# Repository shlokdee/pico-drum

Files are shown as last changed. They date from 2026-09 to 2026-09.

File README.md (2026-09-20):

# pico-drum

rpi pico based midi octapad drum... It uses piezos to sense a tap and outputs midi to your computer. 
Its low cost and really easy to build

## Features:
* 8 pads you can map to any drum piece
* Can play using drum sticks
* connects as midi device to your computer
* screw less, you can connect different pieces together with clips
* tpu pads to stop the ceramic disk from shattering on impact with a drumstick

## CAD Model:

[Onshape link](https://cad.onshape.com/documents/cf409ba0d7730449b32f7b00/w/cda78f4cd7516b803366ff83/e/52d1e4e74febc94aa938617d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) <br><br>
Screenshot From 2026-09-18 23-24-44

There is a base plate, on which there are 8 slots to put your pads
The brown and black pads are printed with TPU, and the piezo sensor is sandwiched between them to ensure that it does not break. The bottom plate mounts the pico, multiplexer and the perf board.

## Schematic
Screenshot From 2026-09-18 15-51-26

Raspberry pi pico has only 3 analog ports, hence we have used a multiplexer to connect 8 drum pads. Piezo emits more than 20 volts when struck hard, which could fry the multiplexer and pico. So we use diodes and resistors to cap the voltage to 3.3 volts, which is safe. The resistors and diodes are mounted on a perf board and it is placed in the bottom plate of the enclosure, along with the pico and the multiplexer...

Screenshot From 2026-09-18 23-11-58

The perf board layout

## Firmware:

Run the command 
```
pip3 install adafruit-circuitpython-midi
```

Then Upload the firmware.py to the pico via this guide: 

[Instructions on how to upload to pico](https://tasnimzotder.medium.com/how-to-write-code-on-pi-pico-using-circuitpython-vs-code-9fd7f0bb5d0a)

You can change what midi commands you want to send with each tap by editing the pad_notes variable in the firmware.py

## How to build
Purchase the components listed in [BOM](BOM.csv)
1. Print the topplate and bottomplate in pla, or any other hard plastic filament.
2. Print the tpupad-Part 1 in 10% infill TPU filament, as we want it to be a bit softer and shock absorbing. Print 8 qty
3. Print the tpupad-Part 2 in 30% infill TPU filament, as it needs to be a bit hard for the drum taps. Print 8 qty
4. Print the clips in TPU 10%, as we need to bend them to fit in place. Print 2 qty
5. Solder in the resistors and the diodes onto the perf board according to the schematic and perf board layout given. Also drill 4 2 mm holes according to the diagram given below...

<br>


6. Place the Pico, mux and the perf board according to the image shown above
7. Place the tpupad-part 1 on the slots provided in the topplate. Then, place your piezo sensors in the circular slot, and route your wires through the holes provided on top. Further, place the tpupad-part 2 on top of the piezo.

Screenshot From 2026-09-18 20-56-39

8. Make all the connections using wires and solder as per the schematic
9. Keep the top plate on top of the bottom plate and secure it using the printed clips.
10. Flash the firmware according to the instructions provided and voila!

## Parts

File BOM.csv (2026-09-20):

Product | Description | qty | unit price | total price | link
Raspberry Pi Pico | MCU; takes in analog from piezo and outputs midi to computer | 1 | ₹384.00 | ₹384.00 | https://robu.in/product/raspberry-pi-pico/
Piezo buzzers | These give out voltage when striked, we use it to detect the drum taps | 8 | ₹20.00 | ₹160.00 | https://robu.in/product/piezo-buzzer-35mm/
Multiplexer (74HC4051) | Pico only has 3 analog ins, so to build octapad, multiplexer is used to connect 8 analog inputs | 1 | ₹ 80.00 | ₹ 80.00 | https://robu.in/product/cjmcu-4051-74hc4051-8-channel-analog-multiplexerdemultiplexer-sensor-module-breakout-board-arduino/
BZX55C3V3 1/2W Zener Diode | piezo generates very high voltage (but low current) when striked, which could fry the mux and pico | 8 | ₹2.00 | ₹16.00 | https://robu.in/product/bzx55c3v3-1-2w-zener-diode-pack-of-40/
1M ohm resistor | used along with zener diode to save the mux and pico | 10 | ₹1.00 | ₹10.00 | https://robu.in/product/mfr-25fte52-1m-yageo-through-hole-resistor-1-mohm-mfr-series-250-mw-%c2%b1-1-axial-leaded-250-v/
1K ohm resistor | used along with zener diode to save the mux and pico | 10 | ₹1.00 | ₹10.00 | https://robu.in/product/1k-ohm-0-25w-metal-film-resistor-pack-of-100/
3d Printed enclosure | It needs a proper enclosure for a finished product | 1 | ₹1100.00 | ₹1100.00 | Robu 3d service
Shipping | getting the products to my home | - | ₹80 | ₹80 | -
Total | - | - | - | ₹1840 | -

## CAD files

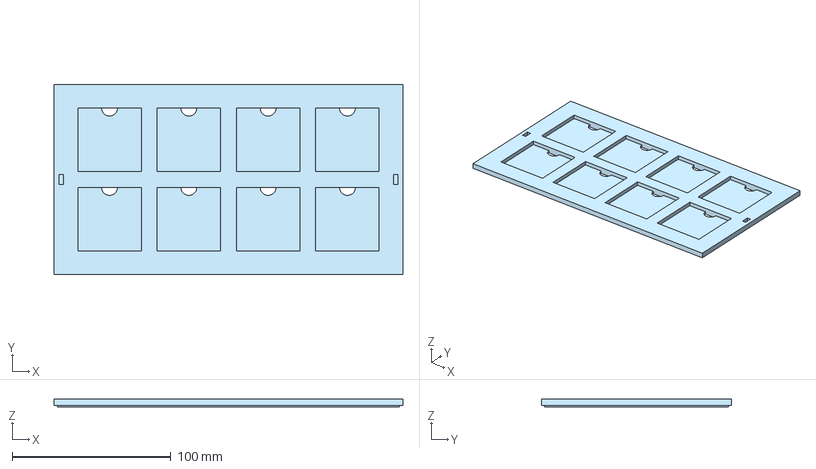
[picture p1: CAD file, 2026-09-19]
step_files/topplate - Part 1.step
220.0 x 120.0 x 5.00 mm

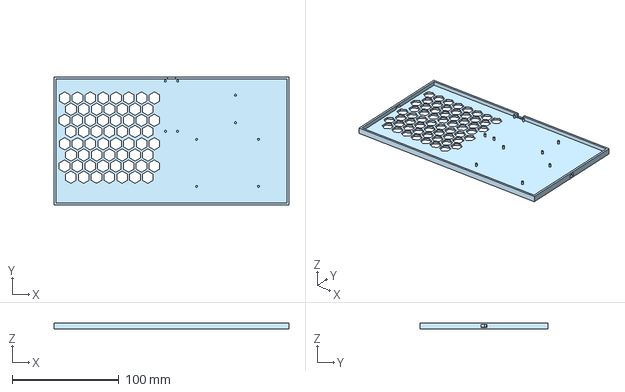
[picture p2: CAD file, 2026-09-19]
step_files/bottomplate - Part 1.step
220.0 x 120.0 x 6.00 mm

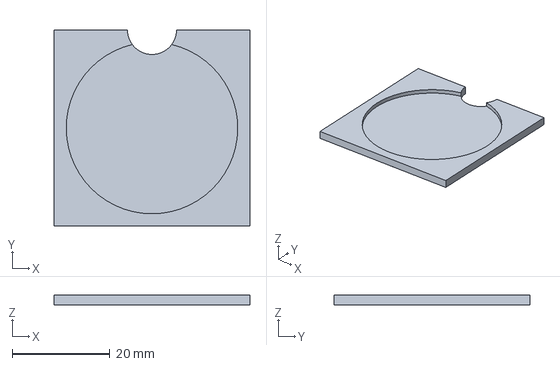
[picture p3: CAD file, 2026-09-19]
step_files/tpupads - Part 1.step
40.0 x 40.0 x 2.00 mm

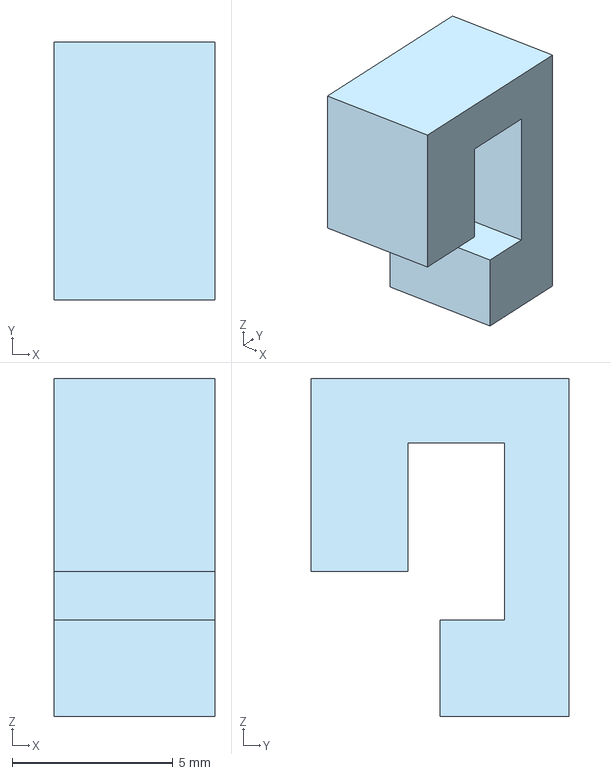
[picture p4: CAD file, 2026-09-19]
step_files/clips - Part 1.step
5.00 x 8.00 x 10.5 mm

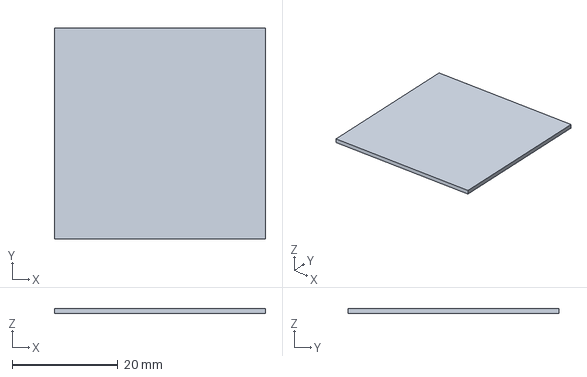
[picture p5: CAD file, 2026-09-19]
step_files/tpupads - Part 2.step
40.0 x 40.0 x 1.00 mm

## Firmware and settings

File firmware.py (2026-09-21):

import time
import board
import digitalio
import analogio
import usb_midi
import adafruit_midi

from adafruit_midi.note_on import NoteOn
from adafruit_midi.note_off import NoteOff
from adafruit_midi.control_change import ControlChange

midi = adafruit_midi.MIDI(midi_out=usb_midi.ports[1], out_channel=0)

pad_notes=[36,38,42,46,49,52,45,48]  #generic drum midi notes, edit this to put your own, or map in the player software...

pad_hit=[False]*8  #checks whether the pad has already been hit, stops from sending multiple midi commands for the same hit

threshhold=5000

#declaring outputs
s0 = DigitalInOut(board.GP16)
s0.direction = Direction.OUTPUT
s1 = DigitalInOut(board.GP17)
s1.direction = Direction.OUTPUT
s2 = DigitalInOut(board.GP18)
s2.direction = Direction.OUTPUT
adc = analogio.AnalogIn(board.GP26)


while True:
  for i in range(8):
    #selects the correct piezo by setting the proper values on the mux
    s0.value(i&1)
    s1.value((i>>1)&1)
    s2.value((i>>2)&1)

    time.sleep_us(100) #delay for mux to not glitch out
    x=adc.value()
    if x>threshhold and not pad_hit[i]:
        vel=min(127, max(1, x // 512))
        midi.send(NoteOn(pad_notes[i], vel))
        pad_hit=True
    elif x<threshhold and pad_hit[i]
        midi.send(NoteOff(pad_notes[i], 0))
        pad_hit=False
  time.sleep_us(10)

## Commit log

2026-09-18 Add Bill of Materials for project components
2026-09-18 added schematic
    [pico-drum_schematics.kicad_pcb, pico-drum_schematics.kicad_sch]
2026-09-19 Update BOM with new costs and shipping details
2026-09-19 added step files and converted bom.md to bom.csv
    [BOM.csv, bottomplate - Part 1.step, clips - Part 1.step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]
2026-09-19 Enhance README with project details and build guide
    Expanded the README with detailed project description, features, CAD model, schematic, and build instructions.
2026-09-19 Modify resistor quantities and update total cost
    Updated quantities and total cost in BOM.csv.
    [BOM.csv]
2026-09-19 Integrate Adafruit MIDI and update GPIO setup
    Refactor firmware to use Adafruit MIDI library for note handling and update pin configurations.
2026-09-19 Update README with CAD model link and image
    Added a link to the CAD model and an image in the README.
2026-09-20 Update BOM.csv with corrected prices and totals
    [BOM.csv]
2026-09-20 Fix formatting of price for 3D printed enclosure
    [BOM.csv]
2026-09-20 Update BOM.csv with new enclosure price and total
    [BOM.csv]
